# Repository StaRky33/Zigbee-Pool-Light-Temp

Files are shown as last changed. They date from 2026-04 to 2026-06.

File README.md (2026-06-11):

# Zigbee Pool Light Temp





Zigbee-enabled pool light controller with integrated NTC temperature sensor. Controls a 12V AC pool light relay while reporting water temperature to Zigbee2MQTT and Home Assistant.
---

## 🌐 Web Builder

**Build and flash your firmware online!**  
Use the [Zigbee Pool Light Temp Web Builder](https://starky33.github.io/Zigbee-Pool-Light-Temp/) to generate and flash custom firmware directly from your browser — no ESP-IDF installation required.

---

## Features

| Feature | Details |
|---|---|
| Integration | Zigbee2MQTT + Home Assistant |
| Temperature Range | -40°C to +85°C (NTC 10kΩ) |
| Relay Control | On/Off via Zigbee (Endpoint 10) |
| Temperature Reporting | Configurable interval (default 5 min) |
| Calibration | Adjustable offset ±10°C, NTC beta coefficient |
| Antenna | External antenna for improved signal strength |

---

## Bill of Materials

| Component | Reference | Price |
|---|---|---|
| Temperature probe | NTC 10kΩ 035HP05202 | ~€10.00 |
| ESP32-C6 | XIAO ESP32-C6 | ~€5.00 |
| Relay module | 5V 1CH optocoupler | ~€2.00 |
| LM2596HV | Step-down regulator | ~€4.00 |
| **Total** | | **~€21.00** |

> **Note**: The Seeed Studio XIAO ESP32C6 includes a built-in antenna connector and external antenna for better range compared to the standard DevKit board.

---

## Hardware

### How it works

The device uses two Zigbee endpoints:

- **Endpoint 10**: On/Off cluster — Relay control (GPIO6)
- **Endpoint 11**: Temperature measurement — NTC probe (GPIO1 ADC)

The ESP32-C6 reads an NTC thermistor via its ADC (GPIO1), applies calibration offsets, and reports the temperature over Zigbee. The relay coil is driven by GPIO6 to switch the 12V AC pool light circuit.

### Wiring

#### Power supply (LM2596HV)

```
12V AC input ──► LM2596HV IN+/IN-
                 LM2596HV OUT+ ──► XIAO ESP32C6 3V3
                 LM2596HV OUT+ ──► Relay VCC
                 LM2596HV OUT- ──► GND (common)
```

#### Relay (GPIO6)

```
XIAO ESP32C6 GPIO6 ──► Relay IN
Relay VCC          ──► 3.3V
Relay GND          ──► GND
Relay COM          ──► 12V AC (load)
Relay NO           ──► Pool LED 12V AC terminal
```

#### NTC temperature probe (GPIO1)

```
3.3V (XIAO 3V3)
  │
  10kΩ  (1% reference resistor)
  │
  ├──── GPIO1 (ADC1_CH0 on XIAO ESP32C6)
  │
[NTC 10kΩ probe]
  │
GND
```

> ⚠️ **IMPORTANT**: Never exceed 3.3V on the ESP32-C6 ADC pin. The XIAO ESP32C6 operates at 3.3V logic level.

---

## Zigbee endpoints

| Endpoint | Cluster | Role | GPIO |
|---|---|---|---|
| 10 | On/Off (0x0006) | Relay control | GPIO6 |
| 11 | Temperature Measurement (0x0402) | NTC reading | GPIO1 |

---

## Software requirements

| Requirement | Version |
|---|---|
| ESP-IDF | 5.1+ |
| Python | 3.8+ |
| Zigbee2MQTT | 1.36+ |

---

## Build & flash

```bash
# Clone the repository
git clone https://github.com/StaRky33/Zigbee-Pool-Light-Temp.git
cd Zigbee-Pool-Light-Temp

# Set target (ESP32-C6)
idf.py --preview set-target esp32c6

# Erase flash before first use
idf.py -p /dev/ttyUSB0 erase-flash

# Build and flash
idf.py -p /dev/ttyUSB0 flash monitor
```

> **Note**: Replace `/dev/ttyUSB0` with your serial port (e.g., `COM3` on Windows, `/dev/cu.usbserial-*` on macOS).

---

## Configuration

### NTC Beta parameter

The NTC beta coefficient relates the thermistor's resistance to temperature. The default value of 3950 works for most 10kΩ NTC sensors.

For field calibration:
1. Measure resistance at 0°C (ice water) → R0
2. Measure resistance at 100°C (boiling water) → R100
3. `Beta = ln(R0 / R100) / (1/273.15 - 1/373.15)`

### GPIO assignments

| Constant | File | Default | Description |
|---|---|---|---|
| `RELAY_GPIO` | `main/relay.h` | GPIO6 | Relay control (was GPIO4 in v1.0.0) |
| `NTC_GPIO` | `main/ntc.h` | GPIO1 | NTC ADC input |

---

## Zigbee2MQTT integration

### Exposed entities

| Entity | Type | Cluster | Endpoint | Access |
|---|---|---|---|---|
| `state` | Switch (on/off) | genOnOff | 10 | R/W |
| `temperature` | Temperature (°C) | msTemperatureMeasurement | 11 | R |
| `temperature_offset` | Numeric (±10°C) | msTemperatureMeasurement (0xFF00) | 11 | R/W |
| `ntc_beta` | Numeric (3000-5000 K) | msTemperatureMeasurement (0xFF01) | 11 | R/W |
| `fw_version` | Text | genBasic | - | R |

### Setting temperature offset

From Home Assistant or via MQTT:

```yaml
# Add +0.50°C to temperature reading
service: mqtt.publish
data:
  topic: zigbee2mqtt/PoolLightTemp/set
  payload: '{"temperature_offset": 0.50}'
```

```yaml
# Subtract -1.00°C from temperature reading
service: mqtt.publish
data:
  topic: zigbee2mqtt/PoolLightTemp/set
  payload: '{"temperature_offset": -1.00}'
```

### Setting NTC beta coefficient

```yaml
# Update NTC beta for your specific probe
service: mqtt.publish
data:
  topic: zigbee2mqtt/PoolLightTemp/set
  payload: '{"ntc_beta": 3950}'
```

---

## Project structure

```
Zigbee-Pool-Light-Temp/
├── CMakeLists.txt
├── external_converters/
│   └── poolLightTemp.mjs          # Zigbee2MQTT external converter
├── main/
│   ├── CMakeLists.txt
│   ├── esp_zb_pool.c              # Main Zigbee application
│   ├── esp_zb_pool.h              # Headers & constants
│   ├── ntc.h                      # NTC temperature sensor
│   ├── relay.h                    # Relay control
│   └── version.h                  # Firmware version
└── manifest.json                  # ESP-IDF manifest
```

---

## Changelog

### v1.0.1 (2025-06-11)
- **Hardware**: Replaced ESP32-C6 DevKit with Seeed Studio XIAO ESP32C6 (with external antenna)
- **GPIO**: Changed relay control from GPIO4 to GPIO6
- **Firmware**: Added report_interval attribute (0xFF02) for configurable reporting
- **Converter**: Added graceful error handling for unsupported attributes

### v1.0.0 (2025-XX-XX)
- Initial release
- ESP32-C6 DevKit board
- GPIO4 for relay control

---

## License

Apache License 2.0 — see [LICENSE](LICENSE).

---

## Support

For issues and questions:
- GitHub Issues: https://github.com/starkydiy/Zigbee-Pool-Light-Temp/issues
- Zigbee2MQTT Community: https://community.zigbee2mqtt.io/

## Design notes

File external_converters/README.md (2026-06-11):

# PoolLightTemp — Zigbee2MQTT External Converter




External converter for the Seeed Studio XIAO ESP32C6 pool controller running Zigbee firmware v1.0.1+.

## Exposed entities

| Entity | Type | Zigbee Cluster | Description |
|---|---|---|---|
| `state` | Switch | genOnOff (0x0006) | Pool light on/off control (Endpoint 10) |
| `temperature` | Temperature (°C) | msTemperatureMeasurement (0x0402) | NTC temperature reading (Endpoint 11) |
| `temperature_offset` | Numeric (±10°C) | msTemperatureMeasurement (0xFF00) | Temperature calibration offset |
| `ntc_beta` | Numeric (K) | msTemperatureMeasurement (0xFF01) | NTC thermistor beta coefficient |
| `report_interval` | Numeric (min) | msTemperatureMeasurement (0xFF02) | Temperature report interval |
| `fw_version` | Text | genBasic (0x0000) | Firmware version string |

## Custom attributes

The device implements three manufacturer-specific attributes on Endpoint 11:

| Attribute ID | Name | Type | Range | Default | Description |
|---|---|---|---|---|---|
| 0xFF00 | temperature_offset | S16 | -100 to +100 (×0.1°C) | 0 | Temperature calibration (±10°C) |
| 0xFF01 | ntc_beta | U16 | 3000-5000 | 3950 | NTC beta coefficient in Kelvin |
| 0xFF02 | report_interval | U8 | 1-60 | 5 | Reporting interval in minutes |

> **Note**: The `temperature_offset` value is stored in units of 0.1°C. A value of 50 represents +5.0°C.

## Installation

### 1. Copy the converter file

Copy `poolLightTemp.mjs` to your Zigbee2MQTT external converters directory:

```
/config/zigbee2mqtt/           ← Z2M config directory
└── external_converters/
    └── poolLightTemp.mjs      ← this file
```

### 2. Edit `configuration.yaml`

Add the external converter to your Zigbee2MQTT configuration:

```yaml
external_converters:
  - poolLightTemp.mjs
```

### 3. Restart Zigbee2MQTT

Restart the addon or the Zigbee2MQTT service:

```bash
# If running as Home Assistant addon
Restart the "Zigbee2MQTT" addon

# If running as standalone
sudo systemctl restart zigbee2mqtt
```

### 4. Re-pair the device

If the device was previously paired, you'll need to force remove it and re-pair:

1. Go to Zigbee2MQTT → Settings → Devices
2. Find your PoolLightTemp device
3. Click "Force Remove"
4. Put the device in pairing mode (reset or power cycle)
5. The device should be discovered with the new converter

---

## Configuration

### Setting temperature offset

Offset the temperature reading to compensate for sensor placement or calibration:

```yaml
# MQTT service call in Home Assistant
service: mqtt.publish
data:
  topic: zigbee2mqtt/PoolLightTemp/set
  payload: '{"temperature_offset": 0.50}'   # +0.50°C
```

```yaml
# Subtract 1°C
service: mqtt.publish
data:
  topic: zigbee2mqtt/PoolLightTemp/set
  payload: '{"temperature_offset": -10}'    # -1.0°C (stored as -10 = -1.0°C)
```

### Setting NTC beta coefficient

Update the beta coefficient if using a different NTC thermistor:

```yaml
service: mqtt.publish
data:
  topic: zigbee2mqtt/PoolLightTemp/set
  payload: '{"ntc_beta": 3950}'   # Default 10kΩ NTC beta value
```

Common beta values:
- 3950 — Most common 10kΩ NTC thermistors
- 3435 — General purpose 10kΩ NTC
- 4250 — High-temperature NTC sensors

### Setting report interval

Change how often the device reports temperature (1-60 minutes):

```yaml
service: mqtt.publish
data:
  topic: zigbee2mqtt/PoolLightTemp/set
  payload: '{"report_interval": 10}'   # Report every 10 minutes
```

> **Note**: Changing the report interval requires firmware v1.0.1 or newer.

### Reading current values

Query the current settings:

```yaml
# Get current temperature offset
service: mqtt.publish
data:
  topic: zigbee2mqtt/PoolLightTemp/get
  payload: '{"temperature_offset": ""}'
```

```yaml
# Get current NTC beta
service: mqtt.publish
data:
  topic: zigbee2mqtt/PoolLightTemp/get
  payload: '{"ntc_beta": ""}'
```

---

## Home Assistant integration

After pairing, the device will appear in Home Assistant with the following entities:

### Device info
- **Model**: PoolLightTemp
- **Manufacturer**: STARKYDIY
- **Firmware**: Displayed in entity state

### Entities

| Entity ID | Type | Description |
|---|---|---|
| `switch.poollighttemp` | Switch | Pool light on/off |
| `sensor.poollighttemp_temperature` | Temperature | Water temperature |
| `sensor.poollighttemp_fw_version` | Sensor | Firmware version |
| `number.poollighttemp_temperature_offset` | Number | Temperature offset |
| `number.poollighttemp_ntc_beta` | Number | NTC beta coefficient |

### Automation example

```yaml
automation:
  - alias: "Pool temperature alert"
    trigger:
      - platform: numeric_state
        entity_id: sensor.poollighttemp_temperature
        above: 30
    action:
      - service: notify.mobile_app
        data:
          message: "Pool water temperature above 30°C!"
```

---

## Troubleshooting

### Device not discovered with converter

If the device pairs but doesn't show the custom entities:

1. Check Zigbee2MQTT logs for converter loading errors
2. Ensure the file name matches exactly (case-sensitive)
3. Verify `external_converters` path in configuration.yaml

### Configuration fails with UNSUPPORTED_ATTRIBUTE

If you see errors reading custom attributes during configuration:

- This is normal on first pairing — the attributes will be created after the first write
- The converter handles this gracefully and won't fail device configuration

### Temperature readings seem off

1. Check NTC probe wiring and connections
2. Verify the 10kΩ reference resistor is correctly connected
3. Adjust `temperature_offset` to compensate for installation location
4. If using a different NTC probe, update `ntc_beta` to match its specifications

---

## Firmware version compatibility

| Converter Version | Firmware Version | Notes |
|---|---|---|
| 1.0.0 | 1.0.0 | Original release, temperature_offset & ntc_beta only |
| 1.0.1 | 1.0.1 | Added report_interval, improved error handling |

---

## Changelog

### v1.0.1
- Added `report_interval` attribute (0xFF02) for configurable temperature reporting
- Improved error handling for unsupported attributes during configuration
- Better attribute ID compatibility (checks both 0xFFxx and decimal formats)

### v1.0.0
- Initial release
- Temperature offset (0xFF00) and NTC beta (0xFF01) attributes
- Basic read/write support for all custom attributes

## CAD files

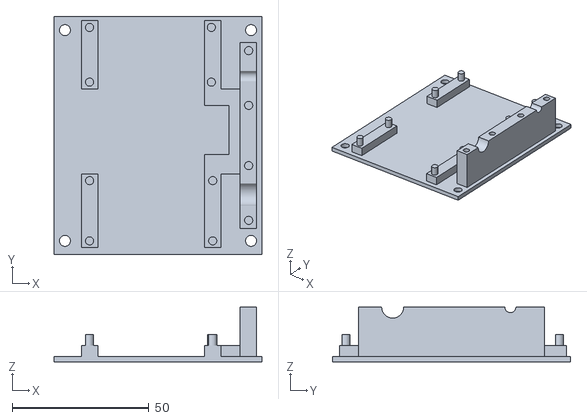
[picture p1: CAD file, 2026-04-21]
stl/PoolLightTempCarrier.stl
76.0 x 87.0 x 20.0

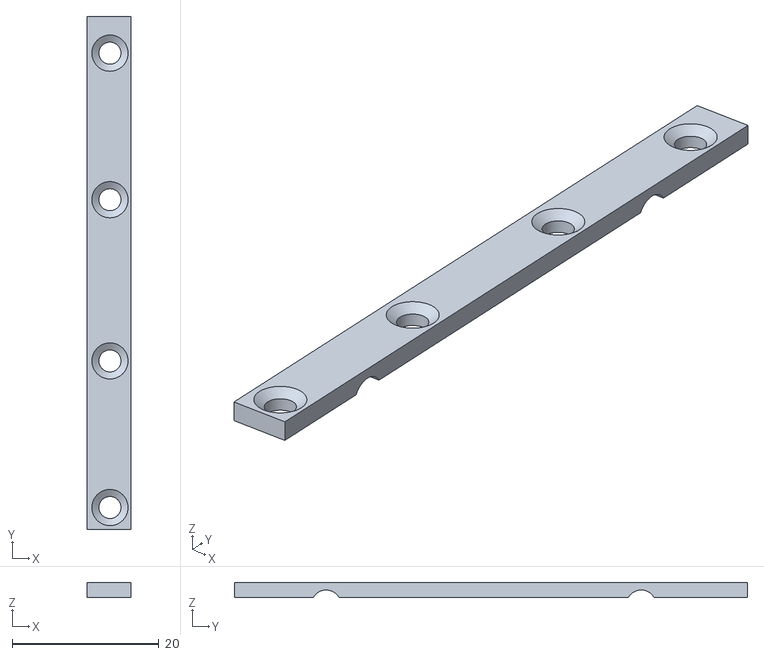
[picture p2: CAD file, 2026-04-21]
stl/PoolLightTempTopScrew.stl
6.00 x 70.0 x 2.00

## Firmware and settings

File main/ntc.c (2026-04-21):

#include "ntc.h"
#include "esp_adc/adc_oneshot.h"
#include "esp_adc/adc_cali.h"
#include "esp_adc/adc_cali_scheme.h"
#include "esp_log.h"
#include <math.h>

static const char *TAG = "NTC";

static adc_oneshot_unit_handle_t s_adc_handle;
static adc_cali_handle_t         s_cali_handle;
static bool                      s_cali_ok = false;

bool ntc_init(void) {
    adc_oneshot_unit_init_cfg_t unit_cfg = {
        .unit_id  = ADC_UNIT_1,
        .ulp_mode = ADC_ULP_MODE_DISABLE,
    };
    ESP_ERROR_CHECK(adc_oneshot_new_unit(&unit_cfg, &s_adc_handle));

    adc_oneshot_chan_cfg_t chan_cfg = {
        .atten    = ADC_ATTEN_DB_12,   // range 0–3.1V
        .bitwidth = ADC_BITWIDTH_12,
    };
    ESP_ERROR_CHECK(adc_oneshot_config_channel(
        s_adc_handle, NTC_ADC_CHANNEL, &chan_cfg));

    adc_cali_curve_fitting_config_t cali_cfg = {
        .unit_id  = ADC_UNIT_1,
        .chan     = NTC_ADC_CHANNEL,
        .atten    = ADC_ATTEN_DB_12,
        .bitwidth = ADC_BITWIDTH_12,
    };
    esp_err_t ret = adc_cali_create_scheme_curve_fitting(
        &cali_cfg, &s_cali_handle);
    s_cali_ok = (ret == ESP_OK);
    if (!s_cali_ok) {
        ESP_LOGW(TAG, "ADC calibration unavailable, using raw mode");
    }
    return true;
}

bool ntc_read(int16_t *temp_hundredths) {
    /* Average 8 samples to reduce ADC noise */
    int32_t sum = 0;
    for (int i = 0; i < 8; i++) {
        int raw;
        ESP_ERROR_CHECK(adc_oneshot_read(
            s_adc_handle, NTC_ADC_CHANNEL, &raw));
        sum += raw;
    }
    int raw_avg = (int)(sum / 8);

    float voltage_mv;
    if (s_cali_ok) {
        int mv;
        adc_cali_raw_to_voltage(s_cali_handle, raw_avg, &mv);
        voltage_mv = (float)mv;
    } else {
        voltage_mv = (raw_avg / NTC_ADC_MAX) * (NTC_VCC * 1000.0f);
    }

    float vcc_mv = NTC_VCC * 1000.0f;
    if (voltage_mv <= 0.0f || voltage_mv >= vcc_mv) {
        ESP_LOGW(TAG, "Voltage out of range: %.1f mV", voltage_mv);
        return false;
    }

    /*
     * Voltage divider: Vout = VCC * R_NTC / (R_REF + R_NTC)
     * → R_NTC = R_REF * Vout / (VCC - Vout)
     */
    float r_ntc = NTC_R_REF * voltage_mv / (vcc_mv - voltage_mv);

    /*
     * Beta form of the Steinhart-Hart equation:
     * 1/T = 1/T0 + (1/Beta) * ln(R/R0)   (T in Kelvin)
     */
    float t0_k   = NTC_T_NOMINAL + 273.15f;
    float ratio  = r_ntc / NTC_R_NOMINAL;
    float temp_k = 1.0f / (1.0f / t0_k + (1.0f / NTC_BETA) * logf(ratio));
    float temp_c = temp_k - 273.15f;

    if (temp_c < -40.0f || temp_c > 125.0f) {
        ESP_LOGW(TAG, "Temperature outside physical range: %.2f°C", temp_c);
        return false;
    }

    *temp_hundredths = (int16_t)(temp_c * 100.0f);
    ESP_LOGD(TAG, "R_NTC=%.0f Ω → %.2f°C", r_ntc, temp_c);
    return true;
}

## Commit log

2026-04-22 Improve temperature behavior with offset.
2026-05-19 Fix wrong GPIO for temp sensor. GPIO1 is ADC_Channel 1.
2026-05-27 Improve download button.
2026-06-12 Fix GPIO 6 for relay and build version 1.0.2

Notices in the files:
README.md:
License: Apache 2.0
